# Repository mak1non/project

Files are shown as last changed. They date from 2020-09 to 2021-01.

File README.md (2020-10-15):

# 卒業研究

画像認識によるライントレースを行う模型車両の作成。

## 内容説明

-   `docs/` : 説明書
-   `sketch/` : 模型車両のソースコード (Arduino)
-   `src/` : 自動運転モジュールのソースコード (Python)
-   `.gitignore` : git リポジトリから除外するファイルの一覧
-   `diagram.fzz` : 回路図 (Fritzing)
-   `LICENSE` : ライセンス (GPL3)
-   `README.md` : この文章
-   `requirements.txt` : Python プログラムの依存モジュール
-   `run.sh` : 実行用スクリプト (非推奨)

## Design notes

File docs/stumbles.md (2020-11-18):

# 困った事など

## 線が上手く読み取れない

線を読み取るために、画像を 2 値化する (白と黒の単純な画像にする) が、その閾値によっては背景の模様を線として読み取ってしまったり、もしくは線を上手く読み取ってくれなかったりする。

これについては、解決方法が存在しないため、実際の実行結果を見ながら閾値を調整していく必要がある。今回のプログラムでは、`config.ini` の `threshold` という変数を書き変えることで閾値を調整することができる。

実際に稼動させる上では、いちいち人間的に閾値を変えることは現実的ではない (人件費が発生してしまう) ため、走行環境に合わせて自ら閾値を変更していく必要があるが、様々な環境を走らせて学習をしていく必要があり、非常に長い期間と手間を掛ける必要がある。

## opencv-python のインストールが終わらない

~~画像解析などを行うために、`OpenCV` と呼ばれるパッケージが必要になる。そのため、`pip3 install opencv-python` を実行して必要なモジュールをインストールするのだが、インストール中に内部で OpenCV 関連のソースコードをコンパイルしているので、それを Raspberry Pi 上で実行すると非常に時間が掛かる。~~

この問題は、piwheels の提供するコンパイル済みの wheels を使用することで解決できる。何らかの理由で piwheels のリポジトリが上手く参照されなかったことが原因と思われる。

### 解決方法

~~Raspberry Pi OS のソフトウェアリポジトリにコンパイル済みの `opencv-python` が用意されているので、それを利用する。~~

Python のような言語において、GNU/Linux ディストリビューションの提供するライブラリパッケージを使用するのはあまり効果的ではない。多少時間が掛かっても `pip` でインストールすべきだ。

## OpenCV がエラーを吐く

OpenCV と web カメラの相性が悪いのか、`Corrupt JPEG data:` から始まるエラー文をずっと出力するため、使用者の混乱を招く可能性がある。

### 使用した workaround

これは OpenCV 側の問題であり、Python のコードを修正することで対処できる問題ではないため、今回は起動用スクリプトを用意し、その中でエラーを表示させないことで対処した。**これは本質的な解決ではないため、あくまで一時的な対処として使用すべきである。**

```
#!/bin/bash

unbuffer python3 src/main.py |& grep --line-buffered -v "Corrupt JPEG data:"
```

このスクリプトを実行するためには、`expect` というパッケージが必要になる。

```
# apt install expect
```

-   出典: [python - OpenCV error on Raspbian: Corrupt jpeg data: 1 extraneous bytes before marker 0xd6 - Stack Overflow](https://stackoverflow.com/questions/42931346/)

## 画面を繋がずにプログラムを実行するとフリーズする

画面を繋がずに Python のプログラムを実行 (SSH 経由) すると、全く入力を受け付けない状態になってしまう。原因が分からないため、テスト時点では画面に接続した状態で実行する必要がある。

### 原因, 回避策

システム上で使用されている GPIO ピンを操作しようとするとフリーズする事が分かった。GPIO 出力を行うためには、システムが使っていない比較的若い番号のピンに接続する必要がある。今回は、そのトラブルを防ぎ、接続を簡略化するために USB 経由でシリアル通信を行うことにした。

## モバイルバッテリーからの電力の供給が安定しない

モバイルバッテリーから、モーター等を駆動させる電源を取るが、その電流 (電圧?) が安定せず、モーターが止まってしまう場合がある。テスト時点では、モバイルバッテリーではなく、コンセント等から供給して対処しているが、単体稼動させる際に、バッテリーをどうするのかはしっかり検討する必要がある。

## シリアル通信の遅延が大きい

コードを改良する前の時点で、操作してから実際に動くまでに約 2 秒の遅延があった。

### 原因, 対処

Arduino 上で文字列を扱うと処理に時間がかかってしまうことがわかった。そのため、送られたデータを文字列として扱うのではなく、byte 型で送られたまま処理することで、全体の処理速度を大幅に上げることに成功した (2 秒 →0.5 秒)。

そのためには、Arduino と Python 両方のプログラムに変更が必要になった。明示的に pySerial で byte 型のデータを送る方法が少し分かりにくいため、下に例を示す。

```py
import serial

# シリアル通信
arduino = serial.Serial(port='/dev/ttyACM0', baudrate=115200)

# 53 (16進数) => 83 (10進数)
# 83 はアルファベットの 'S' を意味するが、別にこの数字に拘る必要は無い
arduino.write(b'\x53')

arduino.flush()
arduino.close()
```

## 未整理

-   上手く曲がらない
-   振動がやばい
-   良い感じに線を引かないといけない
-   車体の設計

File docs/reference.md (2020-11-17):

# 参考文献

## Arduino

Arduino Language Reference
https://www.arduino.cc/reference/en/

## Python

Interface Python and Arduino With PySerial : 3 Steps - Instructables
https://www.instructables.com/Interface-Python-and-Arduino-with-pySerial/

## OpenCV

【寄稿】ぼくの大学院生活を捧げた自動運転ミニカー製作の全て　工学院大学修士1年・鈴木将 | 自動運転ラボ
https://jidounten-lab.com/z_autonomous-mini-car-suzuki-sho

OpenCV 入門編（画像処理と Python）
https://code-graffiti.com/introduction-to-opencv-in-python/

OpenCV+Python で web カメラから画像を取得する - sushi.py
https://crimnut.hateblo.jp/entry/2018/04/04/123147

ロケット花火ランチャーの作り方 - 自作武器を作ろうず
http://teppodone.hatenadiary.jp/entry/howToMakeArduinoTank

ラズパイタンク製作記 〜ハードウェア編〜
https://qiita.com/shi78ge/items/e4d9dd90dc8274431e45

ラズパイタンク製作記 〜ソフトウェア編〜
https://qiita.com/shi78ge/items/882d77ee6f78d63c0b0c

画像処理によるライントレースカー製作記
https://qiita.com/shi78ge/items/d4e8189094588b86a7b2

web カメラ 2 台で距離測定
https://qiita.com/ringo156/items/6c58ed5fae9e56dafefb

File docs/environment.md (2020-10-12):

# 開発環境/実行環境

## 開発環境

### ソフトウェア

-   Windows 10
    -   Visual Studio Code 1.49
-   Ubuntu 20.04
    -   Arduino IDE 1.8
    -   Visual Studio Code 1.49
    -   Python 3.8

### ハードウェア

-   Dell G3 3579
    -   CPU: Intel Core i7-8750H (6 コア/12 スレッド)
    -   RAM: 16GB
-   Raspberry Pi 4 Model B
    -   CPU: Broadcom BCM2711 (4 コア/4 スレッド)
    -   RAM: 2GB

## 実行環境

### ソフトウェア

-   Raspberry Pi OS (32-bit)
    -   Python 3.7
    -   OpenCV 3.2

### ハードウェア

-   Raspberry Pi 4 Model B
    -   CPU: Broadcom BCM2711 (4 コア/4 スレッド)
    -   RAM: 2GB
-   Arduino UNO
-   Logicool C270n

### 模型車両

-   タミヤ 楽しい工作シリーズ
    -   No.100 トラック&ホイールセット (70100)
    -   No.157 ユニバーサルプレート 2枚セット (70157)
    -   No.168 ダブルギヤボックス 左右独立4速タイプ (70168)
-   モータードライバー TA7291P

### 未分類

-   モバイルバッテリー (10000mAh/**3A出力**)
    -   https://www.amazon.co.jp/dp/B0851XFZDL/

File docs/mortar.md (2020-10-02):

# モータードライバーの挙動

使用予定: TA7291P

| IN1 | IN2 | 動作 |
| --- | --- | --- |
| LOW(0)  | LOW(0)  | ストップ |
| HIGH(1) | LOW(0)  | 回転 |
| LOW(0)  | HIGH(1) | 逆回転 |
| HIGH(1) | HIGH(1) | ブレーキ |

- 出典: [モータードライバー(TA7291P)の使い方 [Arduino]](https://www.petitmonte.com/robot/motor_driver_ta7291p.html)

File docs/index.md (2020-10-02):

# 卒業制作

## ドキュメント類

-   [説明書](manual.md)

## メモ類

-   [開発環境/実行環境](environment.md)
-   [モータードライバーの挙動](mortar.md)
-   [参考文献](reference.md)
-   [困った事など](stumbles.md)

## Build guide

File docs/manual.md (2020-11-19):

# 説明書

## 目次

1. [Raspberry Pi のセットアップ](#raspi-setup)
2. [Arduino UNO のセットアップ](#arduino-setup)
3. [配線](#cabling)
4. [車両の組み立て](#assembly)

注: コマンド例の中の `$` は通常ユーザーで実行するコマンド、`#` は特権ユーザーで実行するコマンドを示す。大抵の場合、`sudo` 等を用いる事で特権ユーザーとしての実行が可能。

---

<h2 id="raspi-setup">Raspberry Pi のセットアップ</h2>

自動運転を行うモジュールとして、Raspberry Pi 4 Model B を使用する。この項では、そのセットアップの手順を示す。

### OS イメージ/書き込みソフトの用意

Raspberry Pi 4 Model B を動作させるため、[Raspberry Pi OS](https://www.raspberrypi.org/downloads/) が必要になる。汎用性のために、web ページから OS イメージを直接入手することを強く推奨する。GNU/Linux では `dd` のようなプログラムで OS イメージを書き込むことが出来るが、Windows 環境では、[Rufus](https://rufus.ie/) のようなイメージを書き込むソフトウェアも用意する必要がある。

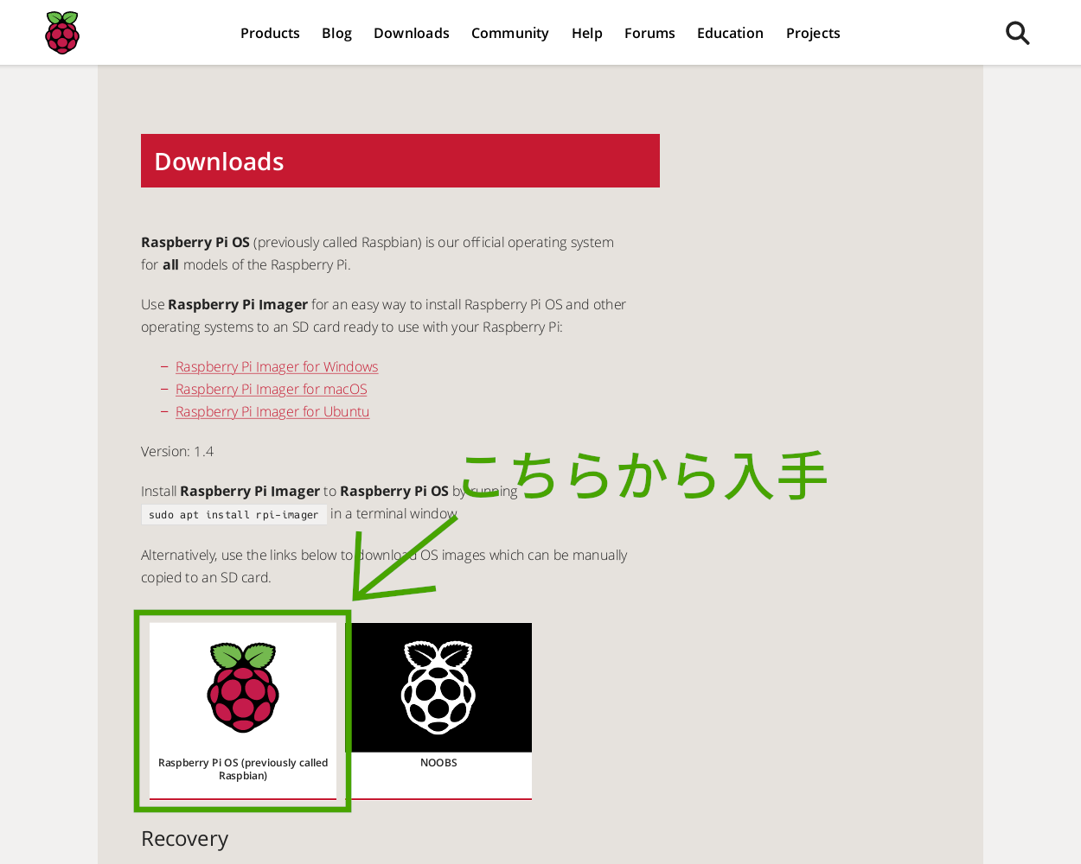
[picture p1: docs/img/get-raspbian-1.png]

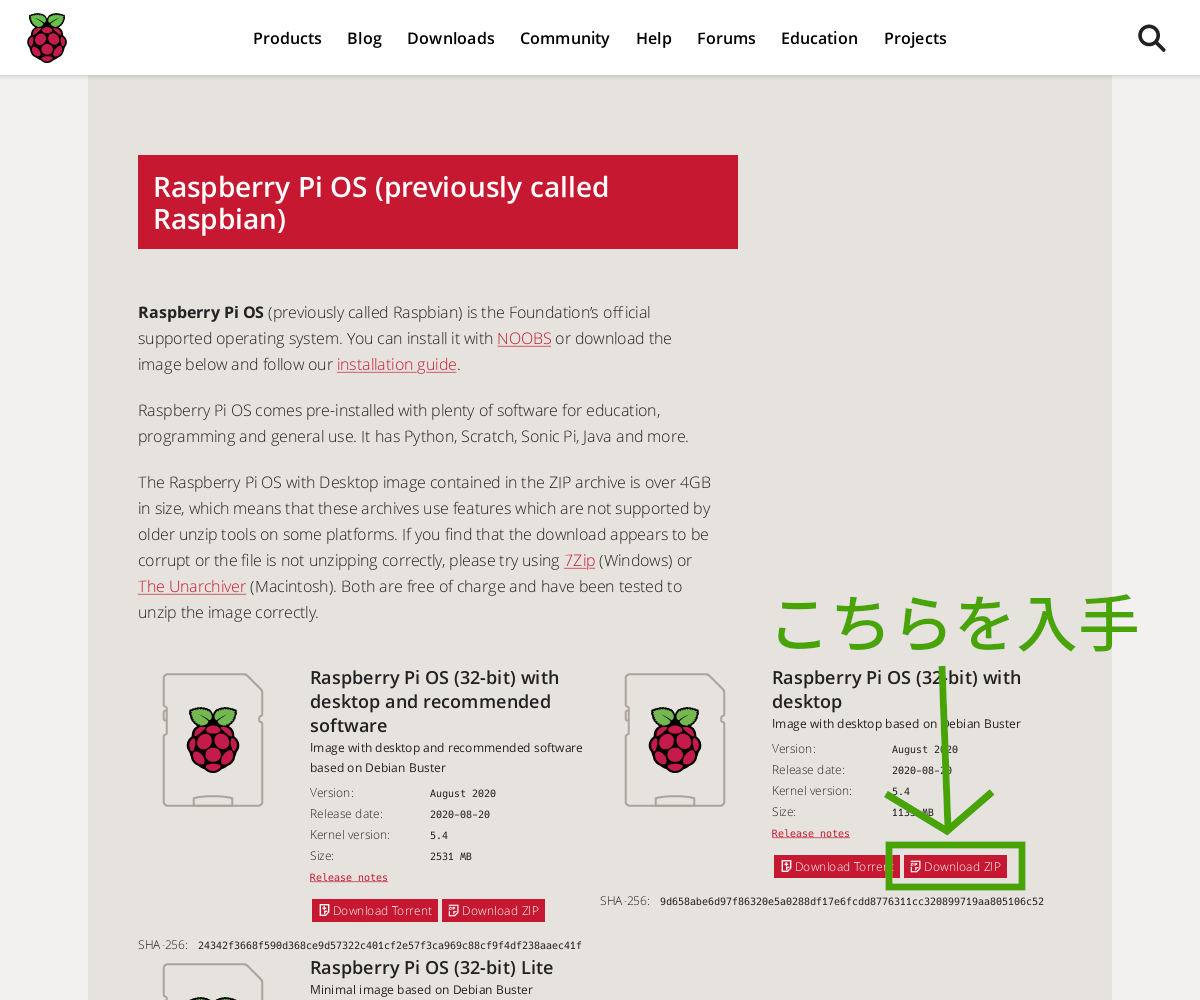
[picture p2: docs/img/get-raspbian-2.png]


### SD カードへの OS の書き込み

GNU/Linux では、以下のコマンドで書き込みをする事ができる。

```
# dd bs=1M if=<Raspberry Pi OS のイメージファイル> of=<SDカード (例: /dev/sdb)>
```

Windows では、Rufus のようなソフトウェアを使用して書き込む。Rufus を起動し、SD カードを選択後、ウィンドウ内にイメージファイルをドラック & ドロップし、\"スタート\"をクリックする。 Rufus 以外のソフトウェアを使用する場合は、各ソフトウェアのドキュメントを参照すること。

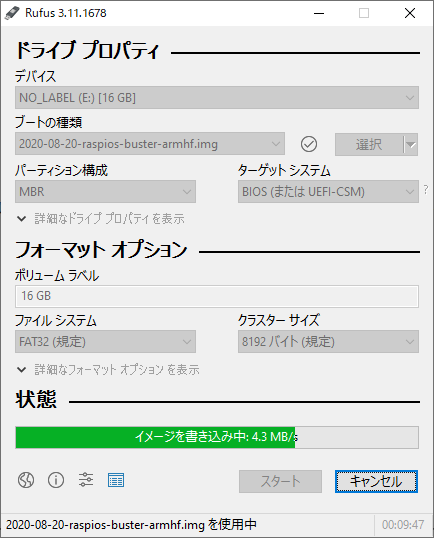
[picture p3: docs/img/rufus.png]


### 実行環境の準備

画面上の指示に従い、OS をセットアップする。

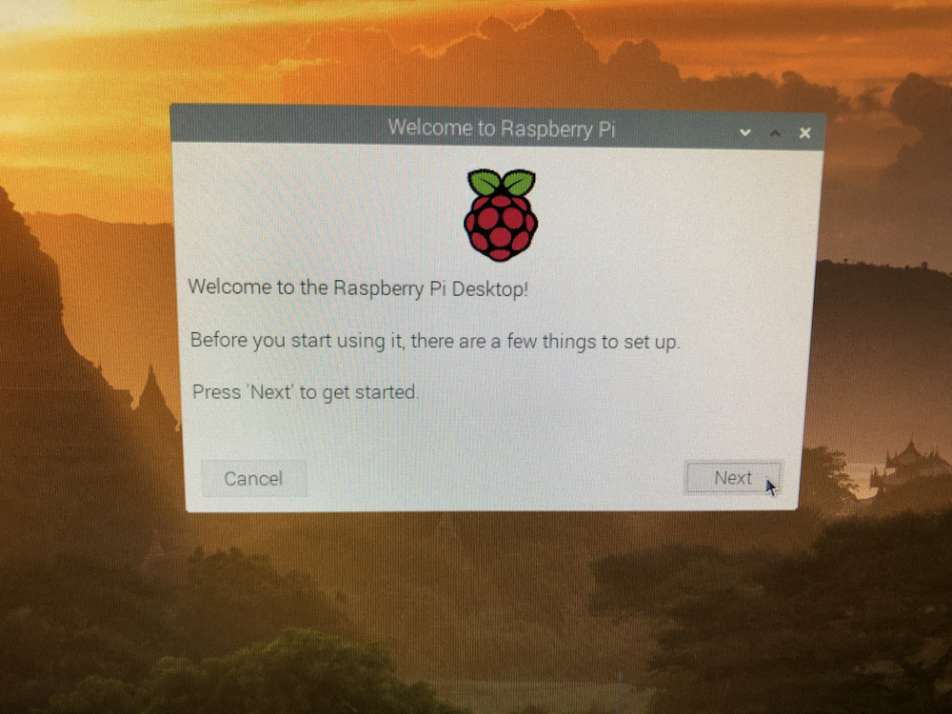
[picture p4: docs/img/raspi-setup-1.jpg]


セットアップ後、端末エミュレータを開き、以下のコマンドを入力して、実行環境の準備を行う (手動で入力するのは大変なので、コピー/ペーストする事を強く推奨する)。これにより、Python3 と OpenCV に必要なソフトウェアを取得する。

```
# apt update
# apt upgrade
# apt install python3 python3-pip python3-venv libaom0 libatk-bridge2.0-0 libatk1.0-0 libatlas3-base libatspi2.0-0 libavcodec58 libavformat58 libavutil56 libbluray2 libcairo-gobject2 libcairo2 libchromaprint1 libcodec2-0.8.1 libcroco3 libdatrie1 libdrm2 libepoxy0 libfontconfig1 libgdk-pixbuf2.0-0 libgfortran5 libgme0 libgraphite2-3 libgsm1 libgtk-3-0 libharfbuzz0b libilmbase23 libjbig0 libmp3lame0 libmpg123-0 libogg0 libopenexr23 libopenjp2-7 libopenmpt0 libopus0 libpango-1.0-0 libpangocairo-1.0-0 libpangoft2-1.0-0 libpixman-1-0 librsvg2-2 libshine3 libsnappy1v5 libsoxr0 libspeex1 libssh-gcrypt-4 libswresample3 libswscale5 libthai0 libtheora0 libtiff5 libtwolame0 libva-drm2 libva-x11-2 libva2 libvdpau1 libvorbis0a libvorbisenc2 libvorbisfile3 libvpx5 libwavpack1 libwayland-client0 libwayland-cursor0 libwayland-egl1 libwebp6 libwebpmux3 libx264-155 libx265-165 libxcb-render0 libxcb-shm0 libxcomposite1 libxcursor1 libxdamage1 libxfixes3 libxi6 libxinerama1 libxkbcommon0 libxrandr2 libxrender1 libxvidcore4 libzvbi0
```

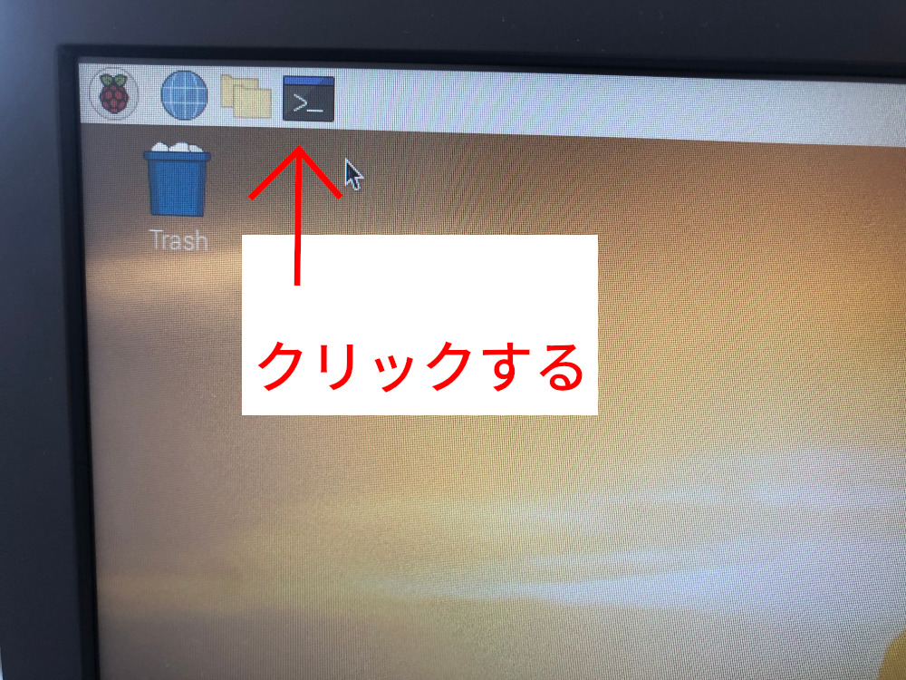
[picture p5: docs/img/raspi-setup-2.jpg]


### コードの準備

Python のプログラムを `scp` コマンドや USB メモリでコピーして、Raspberry Pi 上から実行できるようにする。もしくは、下記のコマンドで GitHub 上のリポジトリからデータを取得しても良い (あらかじめ `git` をインストールしておく必要がある)。

```
$ git clone https://github.com/mak1non/project.git
```

また、GitHub 上のコードに変更があった場合は、コードの存在するディレクトリに移動した上で、以下のコマンドを実行する事で更新が出来る。

```
$ git pull origin master
```

### Python3 仮想環境の準備

Python から OpenCV を使用するためのライブラリをインストールするが、その際、venv と呼ばれる Python 用の仮想環境を作成し、その中にインストールする事を強く推奨する。以下のコマンドをコードの存在するディレクトリ上で実行することで仮想環境の作成、必要なライブラリの取得が可能である。

```
$ python3 -m venv .venv
$ source .venv/bin/activate
$ pip install -r requirements.txt
```

---

<h2 id="arduino-setup">Arduino UNO のセットアップ</h2>

模型車両 (モーター) の制御には、Arduino UNO を利用する。この項では、セットアップ手順を示す。

### 開発環境の準備

模型車両を操作するプログラムを Arduino UNO に書き込むために、Arduino IDE が必要になる。Arduino IDE は、[Arduino の web ページ](https://www.arduino.cc/en/Main/Software)から入手が可能である。Windows 10 であれば、Microsoft Store からも入手が可能である。

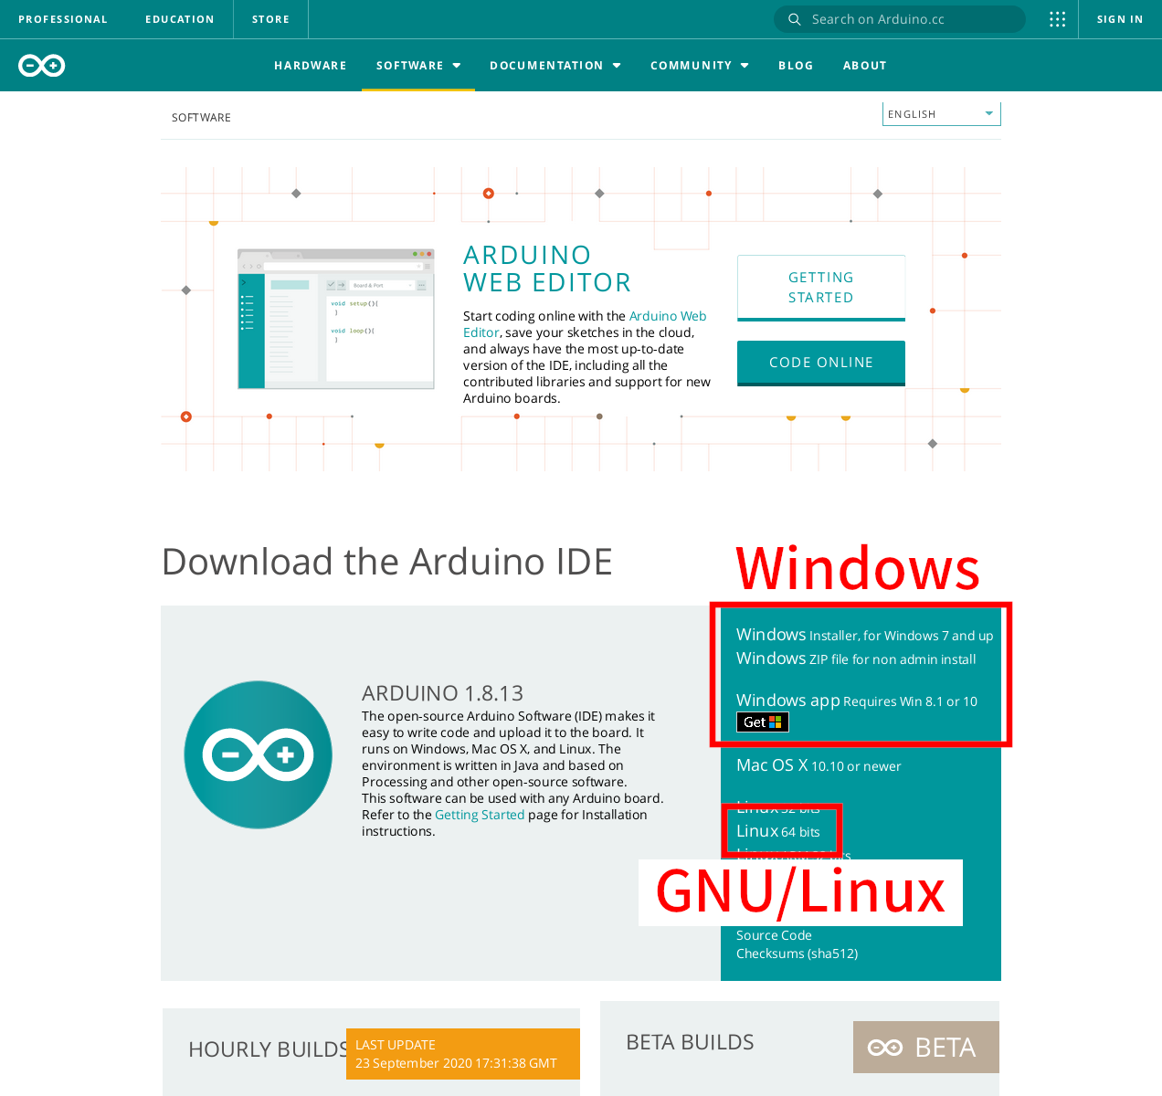
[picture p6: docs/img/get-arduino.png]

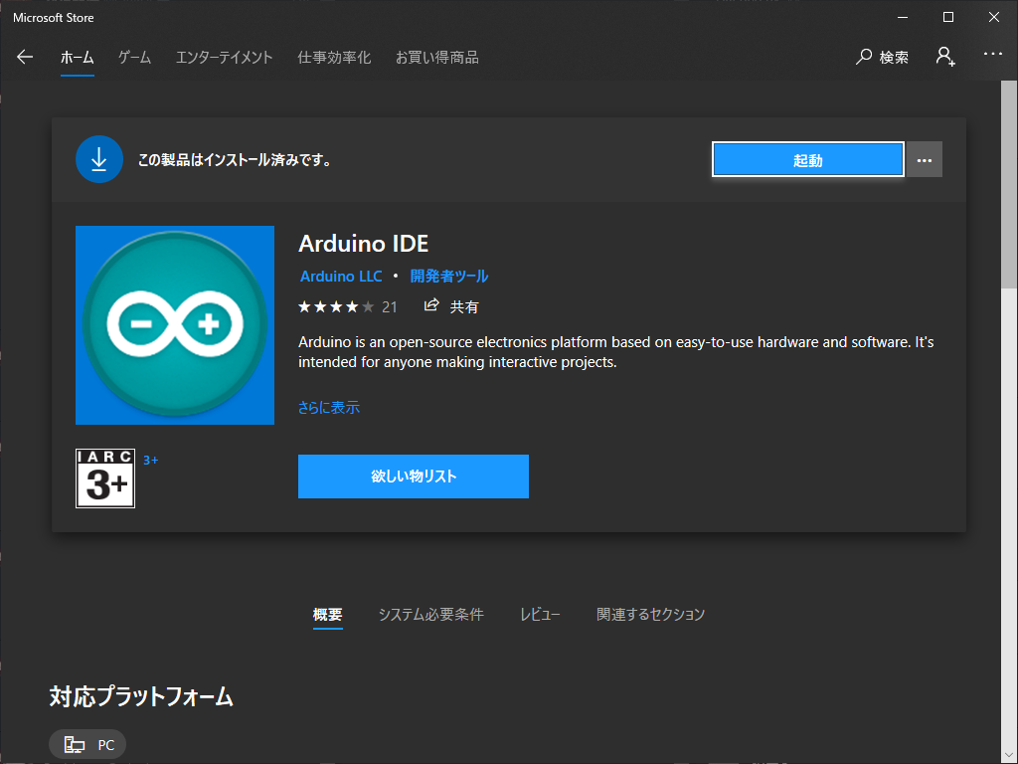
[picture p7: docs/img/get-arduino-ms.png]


GNU/Linux の場合、ダウンロードしたファイルを以下の手順で展開し、インストールする必要がある。

```
$ cd <ファイルの場所>
$ tar xvf arduino-<バージョン番号>-linux64.tar.xz
$ cd arduino-<バージョン番号>
# ./install.sh
# ./arduino-linux-setup.sh <ユーザー名>
```

最後の `arduino-linux-setup.sh` 内での設定を反映させるため、一度 PC を再起動する必要がある。

MacOS を使用する場合は、Arduino 公式のドキュメントを参照すること。

### プログラムの書き込み

まず、スケッチを読み込む。

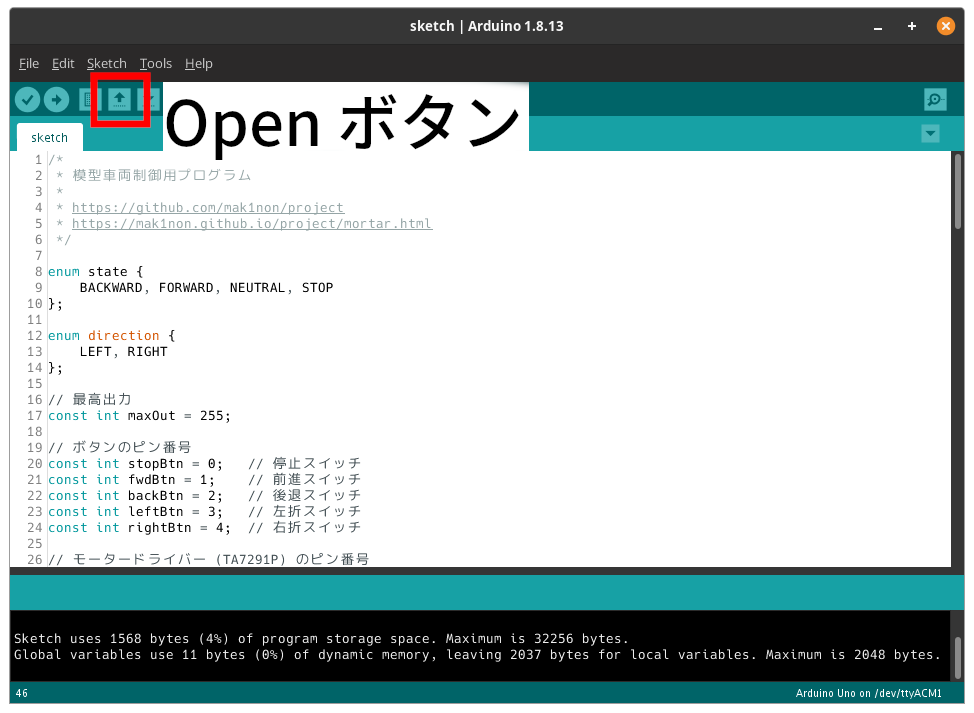
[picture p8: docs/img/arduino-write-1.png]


次に `Tools` タブから、書き込み先の Arduino UNO に合わせた書き込み設定をする。

| 項目名 | 内容 |
| --- | --- |
| Board | Arduino Uno |
| Port | /dev/<接続先> (Arduino Uno) |
| Programmer | AVRISP mkII |

設定した後、1 度 `Sketch -> Verify/Compile` を実行し、プログラムの構文が問題無い事を確認する。確認後、`Sketch -> Upload` で Arduino UNO へプログラムを書き込む。

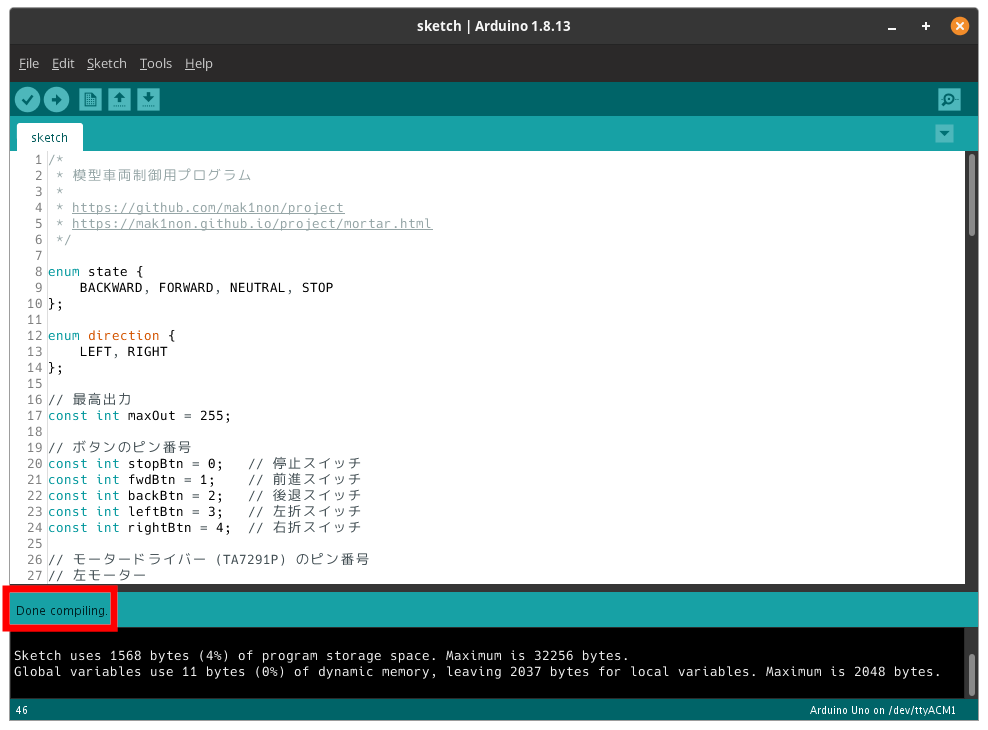
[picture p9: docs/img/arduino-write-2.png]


---

<h2 id="cabling">配線</h2>

製作中

---

<h2 id="assembly">車両の組み立て</h2>

製作中

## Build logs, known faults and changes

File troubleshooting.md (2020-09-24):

# トラブルシューティング

## opencv-python のインストールが終わらない

画像解析などを行うために、`OpenCV` と呼ばれるパッケージが必要になる。そのため、`pip3 install opencv-python` を実行して必要なモジュールをインストールするのだが、インストール中に内部で OpenCV 関連のソースコードをコンパイルしているので、それを Raspberry Pi 上で実行すると非常に時間が掛かる。

### 解決方法

Raspberry Pi OS のソフトウェアリポジトリにコンパイル済みの `opencv-python` が用意されているので、それを利用する。

```
# apt install python3-opencv
```

## 線が上手く読み取れない

線を読み取るために、画像を 2 値化する (白と黒の単純な画像にする) が、その閾値によっては背景の模様を線として読み取ってしまったり、もしくは線を上手く読み取ってくれなかったりする。

これについては、解決方法が存在しないため、実際の実行結果を見ながら閾値を調整していく必要がある。今回のプログラムでは、`line.py` の `threshold` という変数を書き変えることで閾値を調整することができる。

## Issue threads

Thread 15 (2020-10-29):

システムの設計手順

mak1non, 2020-10-29:
中間発表のプレゼン資料で使う。

mak1non, 2020-10-30:
## 駆動系システム

1. 必要な動作をリスト化する
2. その動作に必要なモーターの挙動をまとめる
3. 操作体系を決める
4. プログラムを書く
5. テストする

## 画像認識システム

1. どの条件でどのような場所を走らせるかを決める
2. その判定に必要な処理をまとめる
3. プログラムの流れを決める
4. 実装する
5. テストする

Closed 2020-11-11.

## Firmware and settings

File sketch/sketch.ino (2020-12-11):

/*
 * 模型車両制御用プログラム
 *
 * https://github.com/mak1non/project
 * https://mak1non.github.io/project/mortar.html
 */

enum direction { CENTER, LEFT, RIGHT };

enum state { BACKWARD, FORWARD, STOP };

// 出力
const int count = 5;
const int maxOut = 240;
const int minOut = -220;
const int diff = 10;
int motorOut = 0;

// モータードライバー (TA7291P) のピン番号
// 左モーター
const int leftOut1 = 10;  // 入力1
const int leftOut2 = 9;   // 入力2

// 右モーター
const int rightOut1 = 6;  // 入力1
const int rightOut2 = 5;  // 入力2

// 走行状態
direction carDir = CENTER;
state carState = STOP;

// バッファ
byte buf[2];

void setup() {
    // タイマーの無効化
    TIMSK0 = 0;
    
    // シリアル通信の準備
    Serial.begin(115200);

    // 出力ピンの準備
    pinMode(leftOut1, OUTPUT);
    pinMode(leftOut2, OUTPUT);
    pinMode(rightOut1, OUTPUT);
    pinMode(rightOut2, OUTPUT);

    neutral(500);
    Serial.println("Ready.");
}

void loop() {
    while (true) {
        if (Serial.available() > 0) {
            Serial.readBytesUntil('\n', buf, 1);
            Serial.println(buf[0]);
    
            if (buf[0] == 83) {
                // 停止 (S)
                carState = STOP;
                carDir = CENTER;
            } else if (buf[0] == 65) {
                // 前進 (A)
                carState = FORWARD;
                carDir = CENTER;
            } else if (buf[0] == 66) {
                // 後退 (B)
                carState = BACKWARD;
                carDir = CENTER;
            } else if (buf[0] == 76) {
                // 左折 (L)
                neutral(200);
                carState = FORWARD;
                carDir = LEFT;
            } else if (buf[0] == 82) {
                // 右折 (R)
                neutral(200);
                carState = FORWARD;
                carDir = RIGHT;
            }
        }

        // 現在速度
        if (carState == STOP && motorOut > 0) {
            motorOut -= count;
        } else if (carState == STOP && motorOut < 0) {
            motorOut += count;
        } else if (carState == FORWARD && motorOut < maxOut) {
            motorOut += count;
        } else if (carState == BACKWARD && motorOut > minOut) {
            motorOut -= count;
        }

        // 速度の反映
        if (motorOut == 0) {
            neutral(500);
        } else if (motorOut > 0) {
            if (carDir == LEFT) {
                analogWrite(rightOut1, motorOut - 90);
            } else if (carDir == RIGHT) {
                analogWrite(leftOut1, motorOut - 90);
            } else {
                analogWrite(leftOut1, motorOut);
                analogWrite(rightOut1, motorOut + diff);
            }
        } else if (motorOut < 0) {
            int out = motorOut * -1;
            analogWrite(leftOut2, out);
            analogWrite(rightOut2, out + diff);
        }
    }
}

/*
 * 初期化
 */
void neutral(int wait) {
    if (motorOut > 0) {
        analogWrite(leftOut2, 0);
        analogWrite(rightOut2, 0);
        for (int i = motorOut; i > 0; i -= 5) {
            analogWrite(leftOut1, i);
            analogWrite(rightOut1, i);
        }
    } else if (motorOut < 0) {
        analogWrite(leftOut1, 0);
        analogWrite(rightOut1, 0);
        for (int i = (motorOut * -1); i > 0; i -= 5) {
            analogWrite(leftOut2, i);
            analogWrite(rightOut2, i);
        }
    } else {
        analogWrite(leftOut1, 0);
        analogWrite(leftOut2, 0);
        analogWrite(rightOut1, 0);
        analogWrite(rightOut2, 0);
    }
    delay(wait);
}

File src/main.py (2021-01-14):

#!/usr/bin/env python3

import os
import time
from concurrent.futures import ThreadPoolExecutor
from car import Car
from config import Config
from direction import Direction
from line import Line
from state import State


def main():
    # 画像保存ディレクトリ作成
    os.makedirs('pictures/', mode=0o755, exist_ok=True)

    # 設定の取得
    config = Config()

    # カメラの取得
    line = Line(config)

    # カメラ取得チェック
    if line.camera.isOpened() is False:
        print("Can't open camera.")
        return

    # モーター操作の準備
    with Car() as car:
        print("\n--- 操作方法 ---\n[A]: 開始\n[S]: 一時停止\n[P]: 画像撮影\n[Q]: 終了\n")

        # シリアル通信の準備を待つ
        time.sleep(2)

        # シリアル通信は並列で行う
        with ThreadPoolExecutor(max_workers=1) as executor:
            while True:
                if line.state is State.STANDBY:
                    # 車両に停止状態を伝える
                    car.first = True

                    # 表示のみ
                    line.detectLine(onlyShow=True)
                    line.showImg()

                    # 停止
                    executor.submit(car.run, Direction.STOP)
                elif line.state is State.NORMAL:
                    # 線の認識
                    direction = line.detectLine(
                        currentDirection=car.preDirection)
                    line.showImg()

                    # 判定
                    executor.submit(car.run, direction)
                elif line.state is State.ERROR:
                    # エラー時の表示
                    print('エラー: ' + line.error)
                    break
                elif line.state is State.EXIT:
                    print('終了')
                    break

    # カメラを閉じる
    line.releaseCam()


# 直接起動時のみ処理を実行する
if __name__ == '__main__':
    main()

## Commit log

2020-09-21 Add raspberry pi os image
2020-09-24 Make printDetect() function
2020-09-25 If camera can't open, throw error
    [main.py]
2020-09-25 Error statement, picture scope
    [line.py]
2020-09-30 Add arduino sketch
2020-10-02 Add mortar driver document
2020-10-02 ah (fix & format)
    [sketch.ino]
2020-10-02 Make camera changeable
2020-10-13 Add wiring diagram
    [diagram.fzz]
2020-10-14 Fix error (Not working)
    [sketch.ino]
2020-10-14 Update diagram
    [diagram.fzz]
2020-10-21 Serial communication rework (WIP)
    [sketch.ino]
2020-10-28 Fix can't forward to backword bug
    [sketch.ino]
2020-11-02 Make arduino debuggable
2020-11-10 Change pin
2020-11-13 Revert balance & adjust value
    [sketch.ino]
2020-11-13 Match test code to current spec
2020-12-04 Send signal in separate thread
2020-12-07 もう何変えたかよく分からない
2020-12-10 カーブと停止の挙動を良い感じに変更
2020-12-10 閾値の動的な変更とそれに合わせた設定ファイル類の調整
2020-12-10 閾値とモーターの挙動を調整
2020-12-11 モーターの出力を調整
2021-01-14 停止せずカーブできるように変更
2021-01-14 無駄なif文の削除
2021-01-14 !!!停止優先!!!
